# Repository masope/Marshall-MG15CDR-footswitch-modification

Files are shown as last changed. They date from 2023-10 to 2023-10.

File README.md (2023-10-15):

# Marshall-MG15CD-footswitch-modification-board

This Repository contains PCB design files from KiCAD and source code for modifying Marshall MG15CDR combo guitar amplifier.

## About

Old combo guitar amplifier; Marshall MG15CD, MG15CDR, MG15DFX has 2 Channel; Clean and OD (Overdrive). The amplifier doesn't have footswitch functionality for Channel, Reverb and etc. unlike it's bigger and pricier counterparts.   
   
To give little more life to this good old amplifier, I've designed add-on modification boards to add channel foot-switching functionality by using ATtiny4 MCU.

## controller-board
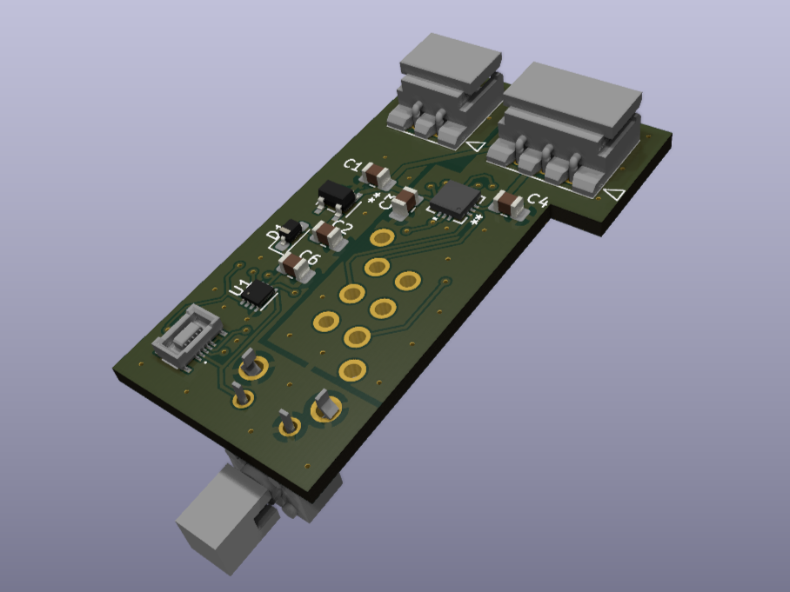
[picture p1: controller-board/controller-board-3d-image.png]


The board for channel switching. It is powered from the **_power-board_**.     

After remove the old channel switch, the board can be installed to amplifier using [DW-01-09-T-S-450](https://www.samtec.com/products/dw-01-09-t-s-450) Board Stacking Headers (adjust post height to 10.5mm).

The MCU can be programmed through [DF40B-10DS-0.4V(58)](https://www.hirose.com/en/product/p/CL0684-4038-8-58) Board-to-Board Connector. If you're finding mating connector's adaptor board, look [my other repository](https://github.com/masope/DF40C-10DP-0.4V-adaptor).

After installation, you can switch between Clean and OD channels using both on-board tactile switch or external footswitch (I recommend unlatch-type switch like "FS-5U"). You might can make a 1/4" jack footswitch connecter to rear side of a chassis or connect footswitch directly to a on-board 2-pin connector both using [50375023](https://www.molex.com/en-us/products/part-detail/50375023). 

## power-board
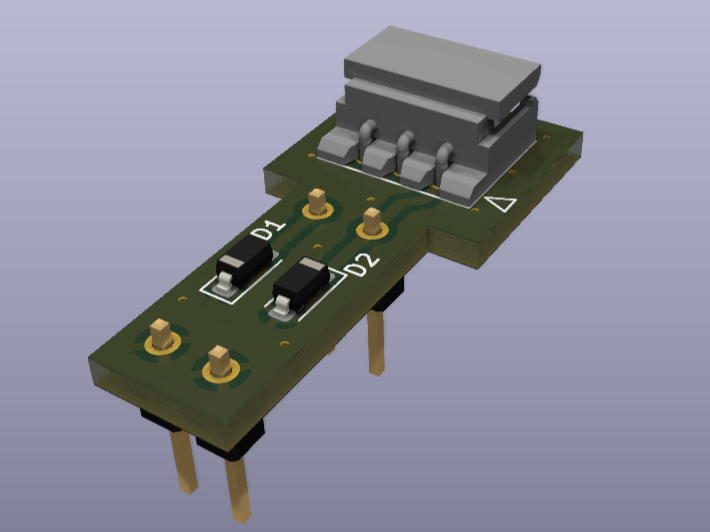
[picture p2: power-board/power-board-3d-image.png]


The Dual 15V Power can be tapped-off from the amplifier's main board.

After remove the Z2, Z3 from the amplifier, install this board.

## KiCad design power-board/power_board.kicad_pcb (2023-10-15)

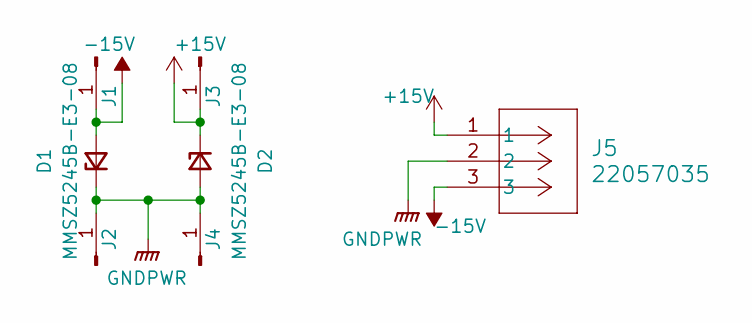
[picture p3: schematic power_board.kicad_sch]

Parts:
D1, D2: MMSZ5245B-E3-08; D_SOD-123
J1, J3: Conn_01x01_Pin; PinHeader_1x01_P1.27mm_Vertical
J2, J4: Conn_01x01_Pin
J5: 22057035; CON_22057035_MOL

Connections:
+15V: D2.1 (K), J3.1, J5.1
-15V: D1.2 (A), J1.1, J5.3
GNDPWR: D1.1 (K), D2.2 (A), J2.1, J4.1, J5.2

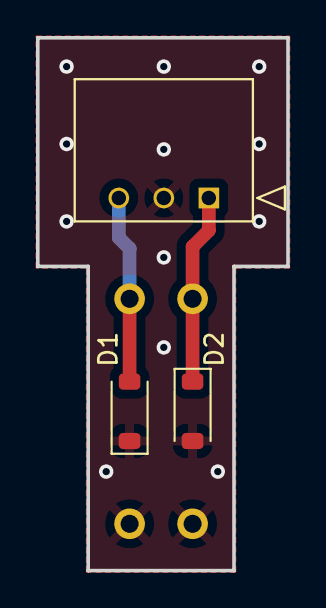
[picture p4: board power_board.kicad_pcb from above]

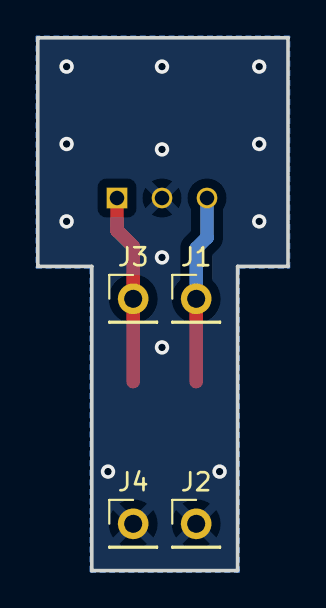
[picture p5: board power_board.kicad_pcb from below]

Board: 2 copper layers, 13.9 x 29.6 mm, 7 parts (4 on the bottom side), 3 nets.

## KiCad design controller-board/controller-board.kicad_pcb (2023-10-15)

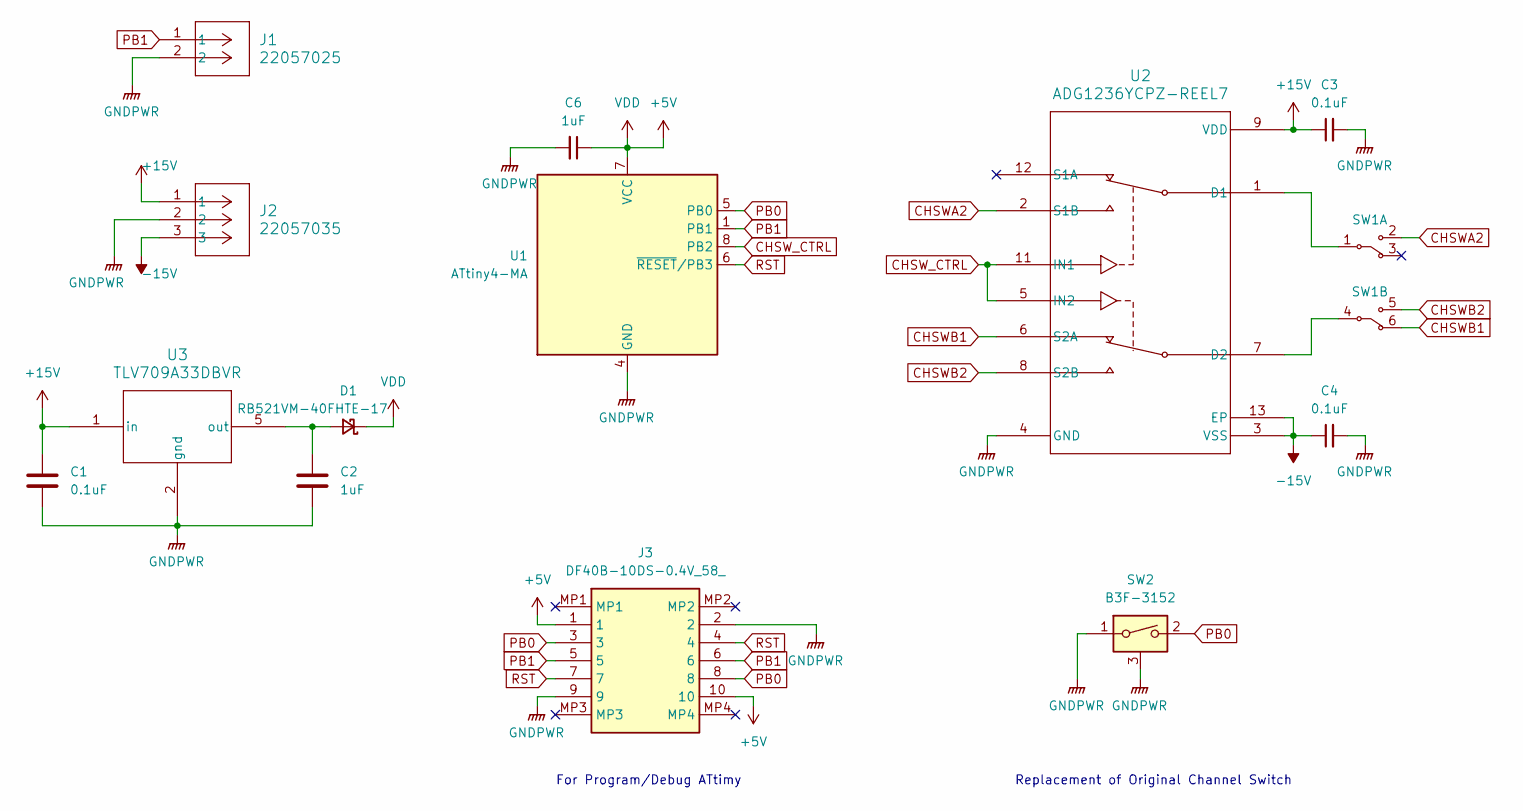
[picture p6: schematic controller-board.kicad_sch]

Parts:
C1, C3, C4: 0.1uF; C_0805_2012Metric_Pad1.18x1.45mm_HandSolder
C2, C6: 1uF; C_0805_2012Metric_Pad1.18x1.45mm_HandSolder
D1: RB521VM-40FHTE-17; D_SOD-323_HandSoldering
J1: 22057025; CON_22057025_MOL
J2: 22057035; CON_22057035_MOL
J3: DF40B-10DS-0.4V_58_; DF40B10DS04V58; Mouser Part Number 798-DF40B10DS0.4V58
SW1: Switch_Toggle_Marshall_DPDT
SW2: B3F-3152; B3F3152; Mouser Part Number 653-B3F-3152
U1: ATtiny4-MA; DFN-8-1EP_2x2mm_P0.5mm_EP0.9x1.5mm
U2: ADG1236YCPZ-REEL7; CP_12_1_ADI
U3: TLV709A33DBVR; SOT-23-5_DBV_TEX

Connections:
+5V: C6.1, D1.1 (K), J3.1, J3.10, U1.7 (VCC)
+15V: C1.1, C3.1, J2.1, U2.9 (VDD), U3.1 (in)
-15V: C4.1, J2.3, U2.3 (VSS), U2.13 (EP)
CHSWA2: SW1.2 (A2), U2.2 (S1B)
CHSWB1: SW1.6 (B3), U2.6 (S2A)
CHSWB2: SW1.5 (B2), U2.8 (S2B)
CHSW_CTRL: U1.8 (PB2), U2.5 (IN2), U2.11 (IN1)
GNDPWR: C1.2, C2.2, C3.2, C4.2, C6.2, J1.2, J2.2, J3.2, J3.9, SW2.1, SW2.3, U1.4 (GND), U2.4 (GND), U3.2 (gnd)
unnamed: C2.1, D1.2 (A), U3.5 (out)
unnamed: SW1.1 (A1), U2.1 (D1)
unnamed: SW1.4 (B1), U2.7 (D2)
PB0: J3.3, J3.8, SW2.2, U1.5 (PB0)
PB1: J1.1, J3.5, J3.6, U1.1 (PB1)
RST: J3.4, J3.7, U1.6 (~RESET/PB3)

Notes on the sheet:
For Program/Debug ATtimy
Replacement of Original Channel Switch

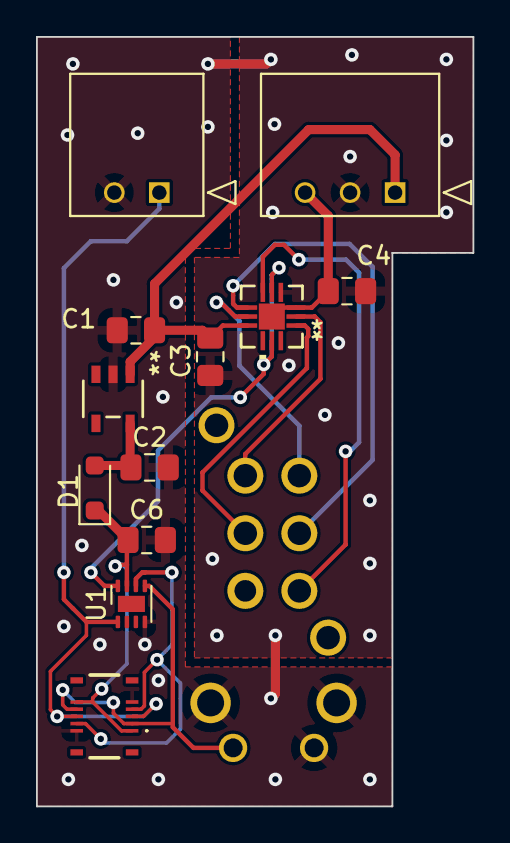
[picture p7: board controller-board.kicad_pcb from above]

Board: 2 copper layers, 24.2 x 42.8 mm, 14 parts (1 on the bottom side), 14 nets.

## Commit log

2023-10-15 finished fisrt design
    [Marshall-MG15CDR-footswitch-modification.kicad_pcb, Marshall-MG15CDR-footswitch-modification.kicad_sch, controller-board.kicad_pcb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]
2023-10-15 updated README.md & image added
    [controller-board.kicad_pcb, controller-board.kicad_sch, power_board.kicad_pcb]
